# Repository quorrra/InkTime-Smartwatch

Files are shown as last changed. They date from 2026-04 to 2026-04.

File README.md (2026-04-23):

# InkTime — Open Source Smartwatch

InkTime is a low-cost, open-source smartwatch designed for extreme battery life and hackability.  
It features a **1.54" E-Paper display**, a **Nordic nRF52840 BLE SoC**, and a high-efficiency power system.

---

## 1) Block Diagram

The hardware architecture revolves around the nRF52840 MCU and a power system designed for month-long battery life.

````text
[ USB Type-C ]                              [ LiPo Battery (250mAh) ]
                 | 5V VBUS                                      |
                 v                                              |
          +---------------+                                     |
          |    BQ25180    | BAT                                 |
          | (Charger IC)  |<------------------------------------+
          +---------------+                                     v
                 | VSYS                                 +---------------+
                 v                                      |   MAX17048    |
          +---------------+                             | (Fuel Gauge)  |
          |    RT6160     |                             +---------------+
          | (Buck-Boost)  |                                     ^
          +---------------+                                     |
                 | 3.3V System Rail (VDD_3V3)                   |
                 |                                              |
 +---------------+----------------------------------------------+-----+
 |               |                                              |     |
 |               v                                              |     |
 |        +-------------+         I2C Bus                       |     |
 |        |  nRF52840   |<======================================+     |
 |        |    MCU      |                                             |
 |        |             |=== I2C ===> [ BMA423 Accelerometer ]        |
 |        |             |=== I2C ===> [ DRV2605L Driver ]-->[ Motor ] |
 |        |             |=== SPI ===> [ 1.54" E-paper Display ]       |
 |        |             |                       ^                      |
 |        |             |-- GPIO (Gate)         | VEPD (Switched Pwr) |
 |        +-------------+      |                |                      |
 |          ^  ^  ^  |         v                |                      |
 |          |  |  |  | +---------------+        |                      |
 +---------(|--|--|)-+-|  PFET Switch  |--------+                      |
            |  |  |  | +---------------+                               |
 [Up]-------+  |  |  |                                                 |
           [Down] |  +--- [ 2.4GHz Antenna ] - - BLE - - [ Companion Phone ]
                  |
              [Enter/Esc]
````

---

## 2) Bill of Materials (BOM)

All components are selected from the JLC Parts library for easy manufacturing and assembly.

| RefDes | Component | Description | JLC Part # | Datasheet |
|---|---|---|---|---|
| U1 | nRF52840 | BLE SoC, Cortex-M4F | [C137156](https://jlcpcb.com/partdetail/C190794) | BLE, Native USB |
| IC1 | BQ25180 | Li-Ion Charger | [C2907455](https://jlcpcb.com/partdetail/C3682423) |Safe USB power-path |
| IC9 | RT6160AWSC | Buck-Boost Converter | [C2834376](https://jlcpcb.com/partdetail/C7065276) | 3.3V System Rail |
| U3 | MAX17048G | I2C Fuel Gauge | [C146603](https://jlcpcb.com/partdetail/C2682616) | 1-Cell Battery Monitor |
| IC3 | BMA423 | 3-axis Accelerometer | [C224345](https://jlcpcb.com/partdetail/C5242966) | Embedded pedometer |
| IC4 | DRV2605YZFR | Haptic Driver | [C146312](https://jlcpcb.com/partdetail/C527464) | For ERM motor |
| J4 | KH-TYPE-C-16P  | USB-C Connector | [C319148](https://jlcpcb.com/partdetail/C7528806) |High-side power switch |

---

## 3) Hardware Functionality

### 3.1 Power Management System
- The watch is powered by a **250mAh LiPo battery**.
- **Charging:** BQ25180 handles USB charging (5V VBUS) and system power-path management.
- **Regulation:** RT6160 buck-boost ensures a stable **3.3V rail** even when battery voltage drops below 3.3V.
- **Fuel Gauge:** MAX17048 uses ModelGauge for accurate **SoC (%)** via I2C, without a sense resistor.

### 3.2 Processing & Connectivity
The **nRF52840** is the central processor, running BLE for smartphone notifications and controlling peripherals over I2C/SPI.

### 3.3 Display & Haptics
- **E-Paper Display:** 1.54", ultra-low power (0W image retention), controlled via SPI.
- **Haptics:** DRV2605 drives an LRA motor for tactile alerts and alarms.

---

## 4) nRF52840 Pin Mapping

| Pin | Signal Name | Interface  | Function |
|---|---|---|---|
| P0.13 | SW_UP | GPIO (In)  | Up navigation button |
| P0.14 | SW_ENT | GPIO (In)  | Enter/Select button |
| P1.02 | SW_DN | GPIO (In)  | Down navigation button |
| P0.08 | I2C_SDA | I2C Data | Shared SDA (IMU, Charger, Gauge, Haptic) |
| P1.09 | I2C_SCL | I2C Clock  | Shared SCL (IMU, Charger, Gauge, Haptic) |
| P0.20 | EPD_RESET | GPIO (Out) | Display hardware reset |
| P0.22 | EPD_BUSY | GPIO (In)  | Display status pin |
| P0.12 | HAPTIC_EN | GPIO (Out) | Enable for DRV2605 haptic driver |
| P0.01 | EPD_DC | GPIO (Out) | Data/Command selector for E-paper |
| P0.03 | EPD_CS | SPI CS | Chip select for E-paper display |

---

## 5) Design & Manufacturing Details

### 5.1 PCB Stackup & Constraints
- **Stackup:** 4-layer PCB (Top, GND Plane, Power Plane, Bottom)
- **Thickness:** 1.0 mm (wearable-friendly)
- **Antenna:** 2.4 GHz PCB antenna at board edge with ground clearance for BLE performance

### 5.2 Component Selection
- **Passives:**  
  - Resistors: 0201 SMD  
  - Capacitors ≤100nF: 0201  
  - Capacitors >100nF: 0402 (unless otherwise specified)
- **Placement:** All components on TOP layer

### 5.3 Routing Rules
- **Power traces** (VCC, VUSB, VBUS, 3V3): 0.3 mm
- **Signal traces:** minimum 0.15 mm
- **Grounding:** solid Layer 2 GND plane + via stitching for EMI/thermal performance

---

## 6) Design Log & Decisions

- **4-layer decision:** moved from 2 to 4 layers to route the 24-pin E-paper connector.
- **GND plane:** Layer 2 kept continuous for RF reference and improved signal integrity.
- **Mechanical fit:** verified in 3D enclosure model (USB-C and buttons aligned with housing).

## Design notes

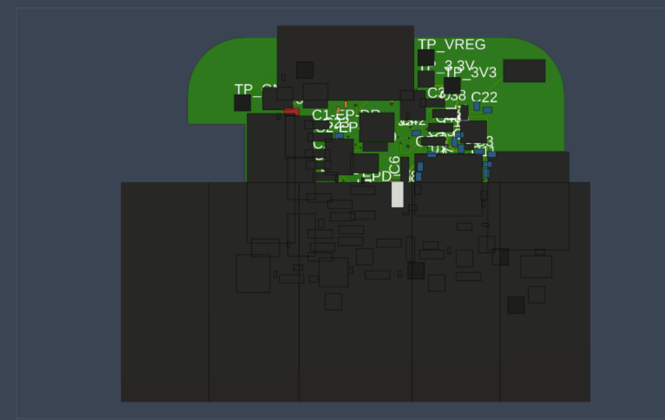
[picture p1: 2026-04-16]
Images/PCB_3D.png

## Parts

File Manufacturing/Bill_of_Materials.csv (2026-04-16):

Qty | Value | Device | Package | Parts | Description | ARROW_PART_NUMBER | ARROW_PRICE-STOCK | AVAILABILITY | CATEGORY | CHECK_PRICES | COPYRIGHT | DATASHEET | DESCRIPTION | DIGI-KEY_PART_NUMBER_1 | DIGI-KEY_PART_NUMBER_2 | DIGI-KEY_PART_NUMBER_3 | FREQUENCY | FREQUENCY_STABILITY | HEIGHT | JLCPCB | LOAD_CAPACITANCE | MANUFACTURER | MANUFACTURER_NAME | MANUFACTURER_PART_NUMBER | MF | MOUSER_PART_NUMBER | MOUSER_PRICE-STOCK | MP | MPN | OPERATING_TEMPERATURE | PACKAGE | PACKAGE_SIZE | PACKAGE_TYPE | PART_STATUS | POPULARITY | PRICE | PROD_ID | PURCHASE-URL | ROHS | SERIES | SNAPEDA_LINK | SPICEMODEL | SPICEPREFIX | SUBCATEGORY | THERMALLOSS | TOLERANCE | TP_SIGNAL_NAME | TYPE | VALUE
1 |  | ESP32_C6_LIBRARY_7_JUMPER_SJ | ESP32_C6_LIBRARY_7_JUMPER_SJ | SJ1 | SMD solder JUMPER |  |  |  |  |  |  |  |  |  |  |  |  |  |  |  |  |  |  |  |  |  |  |  |  |  |  |  |  |  | 3
1 | 0 | CPF0201D7K68C1_CPF0201D7K68C1 | CPF0201D7K68C1_0201 | R3 | 7.68k 0201 Thin Film Surface Mount Fixed Resistor +/-0.5% 0.031W CPF0201D7K68C1
2 | 0 | ERA-1AEB3401C_CPF0201D7K68C1 | ERA-1AEB3401C_0201 | R2, R4 | 7.68k 0201 Thin Film Surface Mount Fixed Resistor +/-0.5% 0.031W CPF0201D7K68C1
4 | 0.1uF | NORDIC_NRF_3_CAPACITOR_0201_L | NORDIC_NRF_3_RESC0201_L | C23, C27, C34, C42 | Generic chip capacitor
1 | 0.1uF/50V | NORDIC_NRF_3_CAPACITOR_0201_L | NORDIC_NRF_3_RESC0201_L | EPD_C5 | Generic chip capacitor
1 | 0.47 | CPF0201D7K68C1_CPF0201D7K68C1 | CPF0201D7K68C1_0201 | R1_EP_DR | 7.68k 0201 Thin Film Surface Mount Fixed Resistor +/-0.5% 0.031W CPF0201D7K68C1
1 | 1.0µF | ESP32_C6_LIBRARY_1_ESP32_WROVER_EAGLE-LTSPICE_CC0402 | ESP32_C6_LIBRARY_1_ESP32_WROVER_EAGLE-LTSPICE_C0402 | C15 | CAPACITOR, European symbol |  |  |  |  |  |  |  |  |  |  |  |  |  |  |  |  |  |  |  |  |  |  |  |  |  |  |  |  |  |  |  |  |  |  |  |  | NONE | C
5 | 100nF | NORDIC_NRF_3_CAPACITOR_0201_L | NORDIC_NRF_3_RESC0201_L | C5, C7, C8, C12, C19 | Generic chip capacitor
1 | 100pF | NORDIC_NRF_3_CAPACITOR_0201_L | NORDIC_NRF_3_RESC0201_L | C11 | Generic chip capacitor
1 | 10K | CPF0201D7K68C1_CPF0201D7K68C1 | CPF0201D7K68C1_0201 | R9 | 7.68k 0201 Thin Film Surface Mount Fixed Resistor +/-0.5% 0.031W CPF0201D7K68C1
4 | 10k | CPF0201D7K68C1_CPF0201D7K68C1 | CPF0201D7K68C1_0201 | R2_EP_DR, R5, R7, R8 | 7.68k 0201 Thin Film Surface Mount Fixed Resistor +/-0.5% 0.031W CPF0201D7K68C1
1 | 10k | ERA-1AEB3401C_CPF0201D7K68C1 | ERA-1AEB3401C_0201 | R_PWR_EPD | 7.68k 0201 Thin Film Surface Mount Fixed Resistor +/-0.5% 0.031W CPF0201D7K68C1
3 | 10uF | ESP32_C6_LIBRARY_1_ESP32_WROVER_EAGLE-LTSPICE_CC0402 | ESP32_C6_LIBRARY_1_ESP32_WROVER_EAGLE-LTSPICE_C0402 | C1-EP-DR, C24, C39 | CAPACITOR, European symbol |  |  |  |  |  |  |  |  |  |  |  |  |  |  |  |  |  |  |  |  |  |  |  |  |  |  |  |  |  |  |  |  |  |  |  |  | NONE | C
1 | 10µH | NORDIC_NRF_2_INDUCTOR_0402_L | NORDIC_NRF_2_RESC0402_L | L2 | Generic chip inductor
4 | 12pF | NORDIC_NRF_3_CAPACITOR_0201_L | NORDIC_NRF_3_RESC0201_L | C1, C2, C17, C18 | Generic chip capacitor
1 | 15nH | NORDIC_NRF_2_INDUCTOR_0402_L | NORDIC_NRF_2_RESC0402_L | L3 | Generic chip inductor
2 | 1pF | NORDIC_NRF_3_CAPACITOR_0201_L | NORDIC_NRF_3_RESC0201_L | C3, C4 | Generic chip capacitor
6 | 1uF | ESP32_C6_LIBRARY_1_ESP32_WROVER_EAGLE-LTSPICE_CC0402 | ESP32_C6_LIBRARY_1_ESP32_WROVER_EAGLE-LTSPICE_C0402 | C29, C30, C31, C32, C37, C38 | CAPACITOR, European symbol |  |  |  |  |  |  |  |  |  |  |  |  |  |  |  |  |  |  |  |  |  |  |  |  |  |  |  |  |  |  |  |  |  |  |  |  | NONE | C
9 | 1uF/50V | ESP32_C6_LIBRARY_1_ESP32_WROVER_EAGLE-LTSPICE_CC0402 | ESP32_C6_LIBRARY_1_ESP32_WROVER_EAGLE-LTSPICE_C0402 | EPD_C1, EPD_C2, EPD_C6, EPD_C7, EPD_C8, EPD_C9, EPD_C10, EPD_C11, EPD_C12 | CAPACITOR, European symbol |  |  |  |  |  |  |  |  |  |  |  |  |  |  |  |  |  |  |  |  |  |  |  |  |  |  |  |  |  |  |  |  |  |  |  |  | NONE | C
1 | 2.2 | CPF0201D7K68C1_CPF0201D7K68C1 | CPF0201D7K68C1_0201 | R_TYPE_SEL | 7.68k 0201 Thin Film Surface Mount Fixed Resistor +/-0.5% 0.031W CPF0201D7K68C1
3 | 2025-10-22_07-23-44_LIBRARY_EVP-AKE31ASW_EVP-AKE31A_PAN | 2025-10-22_07-23-44_LIBRARY_EVP-AKE31ASW_EVP-AKE31A_PAN | 2025-10-22_07-23-44_LIBRARY_SW_EVP-AKE31A_PAN | SW_DN, SW_ENT, SW_UP |  |  |  |  |  |  | Copyright (C) 2025 Ultra Librarian. All rights reserved. |  |  | P123437TR-ND | P123437CT-ND | P123437DKR-ND |  |  |  |  |  |  | Panasonic | EVP-AKE31A
1 | 20V/4.2A/52m?/1.4W | ESP32_C6_LIBRARY_4_ESP32_WROVER_SPARKFUN-DISCRETESEMI_MOSFET_PCH-DMG2305UX-7 | ESP32_C6_LIBRARY_4_ESP32_C6_LIBRARY_4_ESP32_C6_LIBRARY_4_ESP32_C6_LIBRARY_4_ESP32_WROVER_SPARKFUN-DISCRETESEMI_SOT23-3 | Q1 | P-channel MOSFETs |  |  |  |  |  |  |  |  |  |  |  |  |  |  |  |  |  |  |  |  |  |  |  |  |  |  |  |  |  |  |  | TRAN-14388 |  |  |  |  |  |  |  |  |  |  |  | 20V/4.2A/52m?/1.4W
2 | 22uF | ESP32_C6_LIBRARY_1_ESP32_WROVER_EAGLE-LTSPICE_CC0402 | ESP32_C6_LIBRARY_1_ESP32_WROVER_EAGLE-LTSPICE_C0402 | C25, C33 | CAPACITOR, European symbol |  |  |  |  |  |  |  |  |  |  |  |  |  |  |  |  |  |  |  |  |  |  |  |  |  |  |  |  |  |  |  |  |  |  |  |  | NONE | C
1 | 2450AT18B100E_2450AT18B100E | 2450AT18B100E_2450AT18B100E | 2450AT18B100E_ANTC3216X140N | ANT1 | Antennas 2.45GHz ANTENNA | 2450AT18B100E | https://www.arrow.com/en/products/2450at18b100e/johanson-dielectrics?utm_currency=USD&region=nac |  |  |  |  |  | Antennas 2.45GHz ANTENNA |  |  |  |  |  | 1.4mm |  |  |  | JOHANSON TECHNOLOGY | 2450AT18B100E |  | 609-2450AT18B100E | https://www.mouser.co.uk/ProductDetail/Johanson-Technology/2450AT18B100E?qs=yCnrNFeXz%252Bh5MFsFIXGZGA%3D%3D
1 | 3.9nH | NORDIC_NRF_2_INDUCTOR_0402_L | NORDIC_NRF_2_RESC0402_L | L1 | Generic chip inductor
1 | 32.768kHz | 9HT10 | XTAL330X1051X90N | X2 | Crystals 32.768KHz 12.5pF |  |  |  | Crystals |  |  | https://www.txccrystal.com/images/pdf/9ht10.pdf | 32.768 kHz ±20 ppm Crystal 12.5 pF 70 kOhms 2-SMD No Lead |  |  |  | 32.768 kHz | NA |  |  | 12.5 pF | TXC CORPORATION |  |  |  |  |  |  | 9HT10-32.768KDZF-T | -40°C ~ 85°C |  | 2-SMD No Lead | Surface Mount | Active |  |  |  |  | Compliant | 9HT10 |  |  |  | Oscillators |  | ±20 ppm |  | Resonators
1 | 32MHz | NORDIC_NRF_XTAL_32MHZ | NORDIC_NRF_BT-XTAL_2016_N | X1
2 | 3K3 | ERA-1AEB3401C_CPF0201D7K68C1 | ERA-1AEB3401C_0201 | R17, R18 | 7.68k 0201 Thin Film Surface Mount Fixed Resistor +/-0.5% 0.031W CPF0201D7K68C1
1 | 4.7uF | ESP32_C6_LIBRARY_1_ESP32_WROVER_EAGLE-LTSPICE_CC0402 | ESP32_C6_LIBRARY_1_ESP32_WROVER_EAGLE-LTSPICE_C0402 | C43 | CAPACITOR, European symbol |  |  |  |  |  |  |  |  |  |  |  |  |  |  |  |  |  |  |  |  |  |  |  |  |  |  |  |  |  |  |  |  |  |  |  |  | NONE | C
1 | 4.7uF/25V | ESP32_C6_LIBRARY_1_ESP32_WROVER_EAGLE-LTSPICE_CC0402 | ESP32_C6_LIBRARY_1_ESP32_WROVER_EAGLE-LTSPICE_C0402 | C2-EP-DR | CAPACITOR, European symbol |  |  |  |  |  |  |  |  |  |  |  |  |  |  |  |  |  |  |  |  |  |  |  |  |  |  |  |  |  |  |  |  |  |  |  |  | NONE | C
4 | 4.7µF | ESP32_C6_LIBRARY_1_ESP32_WROVER_EAGLE-LTSPICE_CC0402 | ESP32_C6_LIBRARY_1_ESP32_WROVER_EAGLE-LTSPICE_C0402 | C6, C14, C20, C21 | CAPACITOR, European symbol |  |  |  |  |  |  |  |  |  |  |  |  |  |  |  |  |  |  |  |  |  |  |  |  |  |  |  |  |  |  |  |  |  |  |  |  | NONE | C
1 | 47nF | NORDIC_NRF_3_CAPACITOR_0201_L | NORDIC_NRF_3_RESC0201_L | C16 | Generic chip capacitor
1 | 503480-2400_503480-2400 | 503480-2400_503480-2400 | 503480-2400_5034802400 | J1 | FFC & FPC Connectors 0.5mm FPC RA SMT Dual Contact 24Ckt |  |  |  |  |  |  |  | FFC & FPC Connectors 0.5mm FPC RA SMT Dual Contact 24Ckt |  |  |  |  |  | 1.87mm |  |  |  | Molex | 503480-2400 |  | 538-503480-2400 | https://www.mouser.co.uk/ProductDetail/Molex/503480-2400?qs=OAhjpuo3Vu7efIoxFh9AOw%3D%3D
2 | 5k1 | CPF0201D7K68C1_CPF0201D7K68C1 | CPF0201D7K68C1_0201 | R1_USB, R2_USB | 7.68k 0201 Thin Film Surface Mount Fixed Resistor +/-0.5% 0.031W CPF0201D7K68C1
1 | 68uH | NORDIC_NRF_2_INDUCTOR_0402_L | NORDIC_NRF_2_RESC0402_L | L5 | Generic chip inductor
1 | 820pF | NORDIC_NRF_3_CAPACITOR_0201_L | NORDIC_NRF_3_RESC0201_L | C9 | Generic chip capacitor
1 | BMA423_BMA423 | BMA423_BMA423 | BMA423_BMA423 | IC3 | Accelerometers Triaxial low-g 12bit Acceleration Sensor | BMA423 | https://www.arrow.com/en/products/bma423/bosch |  |  |  |  |  | Accelerometers Triaxial low-g 12bit Acceleration Sensor |  |  |  |  |  | 1mm |  |  |  | BOSCH | BMA423 |  | 262-BMA423 | https://www.mouser.co.uk/ProductDetail/Bosch-Sensortec/BMA423?qs=HXFqYaX1Q2xC%252BSgeGoX3mg%3D%3D
1 | BQ25180YBGR_BQ25180YBGR | BQ25180YBGR_BQ25180YBGR | BQ25180YBGR_BGA8C40P2X4_100X155X50 | IC1 | Charger IC Lithium Ion/Polymer, Lithium Iron Phosphate 8-DSBGA (1.6x1.1) | BQ25180YBGR | https://www.arrow.com/en/products/bq25180ybgr/texas-instruments?utm_currency=USD&region=nac |  |  |  |  |  | Charger IC Lithium Ion/Polymer | Lithium Iron Phosphate 8-DSBGA (1.6x1.1) |  |  |  |  |  | 0.5mm |  |  |  | Texas Instruments | BQ25180YBGR |  | 595-BQ25180YBGR | https://www.mouser.co.uk/ProductDetail/Texas-Instruments/BQ25180YBGR?qs=doiCPypUmgEWjAK%252BJAX6Tw%3D%3D
1 | DRV2605YZFR_DRV2605YZFR | DRV2605YZFR_DRV2605YZFR | DRV2605YZFR_BGA9C50P3X3_144X144X62 | IC2 | Haptic Driver for ERM/LRA with Built-In Library and Smart Loop Architecture | DRV2605YZFR | https://www.arrow.com/en/products/drv2605yzfr/texas-instruments?region=nac |  |  |  |  |  | Haptic Driver for ERM/LRA with Built-In Library and Smart Loop Architecture |  |  |  |  |  | 0.625mm |  |  |  | Texas Instruments | DRV2605YZFR
1 | ESP32_C6_LIBRARY_3_USBLC6-2SC6Y | ESP32_C6_LIBRARY_3_USBLC6-2SC6Y | ESP32_C6_LIBRARY_3_SOT95P280X145-6N | D3 | Low Cap. ESD Protection Auto SOT-23-6 STMicroelectronics USBLC6-2SC6Y, Dual Uni-Directional TVS Diode Array, 6-Pin SOT-23 |  |  | In Stock |  | https://www.snapeda.com/parts/USBLC6-2SC6Y/STMicroelectronics/view-part/?ref=eda |  |  | 17V Clamp 5A (8/20µs) Ipp Tvs Diode Surface Mount SOT-23-6 |  |  |  |  |  |  |  |  |  |  |  | STMicroelectronics |  |  | USBLC6-2SC6Y |  |  | SOT-23-6 STMicroelectronics |  |  |  |  | None |  |  |  |  | https://www.snapeda.com/parts/USBLC6-2SC6Y/STMicroelectronics/view-part/?ref=snap
1 | ESP32_C6_LIBRARY_6_SI1308EDL-T1-GE3 | ESP32_C6_LIBRARY_6_SI1308EDL-T1-GE3 | ESP32_C6_LIBRARY_6_SOT65P210X110-3N | Q3 | MOSFET N-Ch 30V 1.5A TrenchFET SC70 Vishay Si1308EDL-T1-GE3 N-channel MOSFET Transistor, 1.5 A, 30 V, 3-Pin SC-70 |  |  | In Stock |  | https://www.snapeda.com/parts/SI1308EDL-T1-GE3/Vishay+Siliconix/view-part/?ref=eda |  |  | Si1308EDL-T1-GE3 N-channel MOSFET Transistor | 1.5 A | 30 V | 3-Pin SC-70 | Siliconix / Vishay SI1308EDL-T1-GE3 |  |  |  |  |  |  |  |  |  |  |  | Vishay Siliconix |  |  | SI1308EDL-T1-GE3 |  |  | SOT-323 Vishay Semiconductor |  |  |  |  | None |  | https://www.snapeda.com/api/url_track_click_mouser/?unipart_id=274603&manufacturer=Vishay Siliconix&part_name=SI1308EDL-T1-GE3&search_term=None |  |  | https://www.snapeda.com/parts/SI1308EDL-T1-GE3/Vishay+Siliconix/view-part/?ref=snap
1 | ESP32_C6_LIBRARY_MAX17048G+T10 | ESP32_C6_LIBRARY_MAX17048G+T10 | ESP32_C6_LIBRARY_SON50P200X200X80-9N | U3 | Check availability |  |  | In Stock |  | https://www.snapeda.com/parts/MAX17048G+T10/Analog+Devices/view-part/?ref=eda |  |  | 3µA 1-Cell/2-Cell Fuel Gauge with ModelGauge |  |  |  |  |  |  |  |  |  |  |  | Analog Devices |  |  | MAX17048G+T10 |  |  | TDFN-8 Maxim |  |  |  |  | None |  | https://www.snapeda.com/api/url_track_click_mouser/?unipart_id=329239&manufacturer=Analog Devices&part_name=MAX17048G+T10&search_term=None |  |  | https://www.snapeda.com/parts/MAX17048G+T10/Analog+Devices/view-part/?ref=snap
14 | HECTOR_WATCH_1_TPTP20R | HECTOR_WATCH_1_TPTP20R | HECTOR_WATCH_1_TP20R | TP_3.3V, TP_3V3, TP_BAT_GND, TP_GND, TP_ON, TP_OP, TP_RESET, TP_SCL, TP_SDA, TP_SWDCLK, TP_SWDIO, TP_SWO, TP_VBAT, TP_VREG | Test pad |  |  |  |  |  |  |  |  |  |  |  |  |  |  |  |  |  |  |  |  |  |  |  |  |  |  |  |  |  | 2
1 | KH-TYPE-C-16P_KH-TYPE-C-16P | KH-TYPE-C-16P_KH-TYPE-C-16P | KH-TYPE-C-16P_KINGHELM_KH-TYPE-C-16P | J3 | Check availability |  |  | Not in stock |  | https://www.snapeda.com/parts/KH-TYPE-C-16P/Kinghelm/view-part/?ref=eda |  |  |  |  |  |  |  |  |  |  |  |  |  |  | kinghelm |  |  | KH-TYPE-C-16P |  |  | None |  |  |  |  | None |  |  |  |  | https://www.snapeda.com/parts/KH-TYPE-C-16P/Kinghelm/view-part/?ref=snap
3 | MBR0530 | ESP32_C6_LIBRARY_5_MBR0530 | ESP32_C6_LIBRARY_5_SOD3716X135N | D2, D4, D5 | ON SEMICONDUCTOR - MBR0530 - DIODE, SCHOTTKY, 0.5A, 30V, SOD-123 |  |  | In Stock |  | https://www.snapeda.com/parts/MBR0530/Onsemi/view-part/?ref=eda |  |  | Diode Schottky 30 V 500mA Surface Mount SOD-123 |  |  |  |  |  |  |  |  |  |  |  | ON Semiconductor |  |  | MBR0530 |  |  | SOD-123-2 ON Semiconductor |  |  |  |  | None |  | https://www.snapeda.com/api/url_track_click_mouser/?unipart_id=179458&manufacturer=ON Semiconductor&part_name=MBR0530&search_term=None |  |  | https://www.snapeda.com/parts/MBR0530/Onsemi/view-part/?ref=snap
1 | MLP2016SR47MT0S1_FTC252012SR47MBCA | MLP2016SR47MT0S1_FTC252012SR47MBCA | MLP2016SR47MT0S1_INDC2016X100N | L7 | SMD / SMT Inductors (Coils), L=0.47?H, L x W x T : |  |  |  |  |  |  |  | SMD / SMT Inductors (Coils) | L=0.47?H | L x W x T : |  |  |  |  |  | 1mm | https://jlcpcb.com/partdetail/6763488-FTC252012SR47MBCA/C5832368 |  |  | TDK | FTC252012SR47MBCA
3 | N.C. | NORDIC_NRF_3_CAPACITOR_0201_L | NORDIC_NRF_3_RESC0201_L | C10, C13, C22 | Generic chip capacitor
1 | NORDIC_NRF_4_NRF52840_QF | NORDIC_NRF_4_NRF52840_QF | NORDIC_NRF_4_AQFN50P700X700X85_HS-74N | U1 | nRF52840
1 | RT6160AWSC_RT6160AWSC | RT6160AWSC_RT6160AWSC | RT6160AWSC_BGA15C40P3X5_140X230X60 | IC9 | Buck-Boost Regulator Positive Output Step-Up/Step-Down I2C DC-DC Controller IC 15-WL-CSP (BSC) (1.4x2.3) |  |  |  |  |  |  |  | Buck-Boost Regulator Positive Output Step-Up/Step-Down I2C DC-DC Controller IC 15-WL-CSP (BSC) (1.4x2.3) |  |  |  |  |  | 0.6mm |  |  |  | RICHTEK | RT6160AWSC |  | 835-RT6160AWSC | https://www.mouser.co.uk/ProductDetail/Richtek/RT6160AWSC?qs=amGC7iS6iy%2FLd9PSoixZXQ%3D%3D
1 | TC2030-IDC_TC2030-IDC | TC2030-IDC_TC2030-IDC | TC2030-IDC_TC2030IDC | J2 | CABLE ADAPTER 6 POS |  |  |  |  |  |  |  | CABLE ADAPTER 6 POS |  |  |  |  |  | 19mm |  |  |  | Tag Connect | TC2030-IDC

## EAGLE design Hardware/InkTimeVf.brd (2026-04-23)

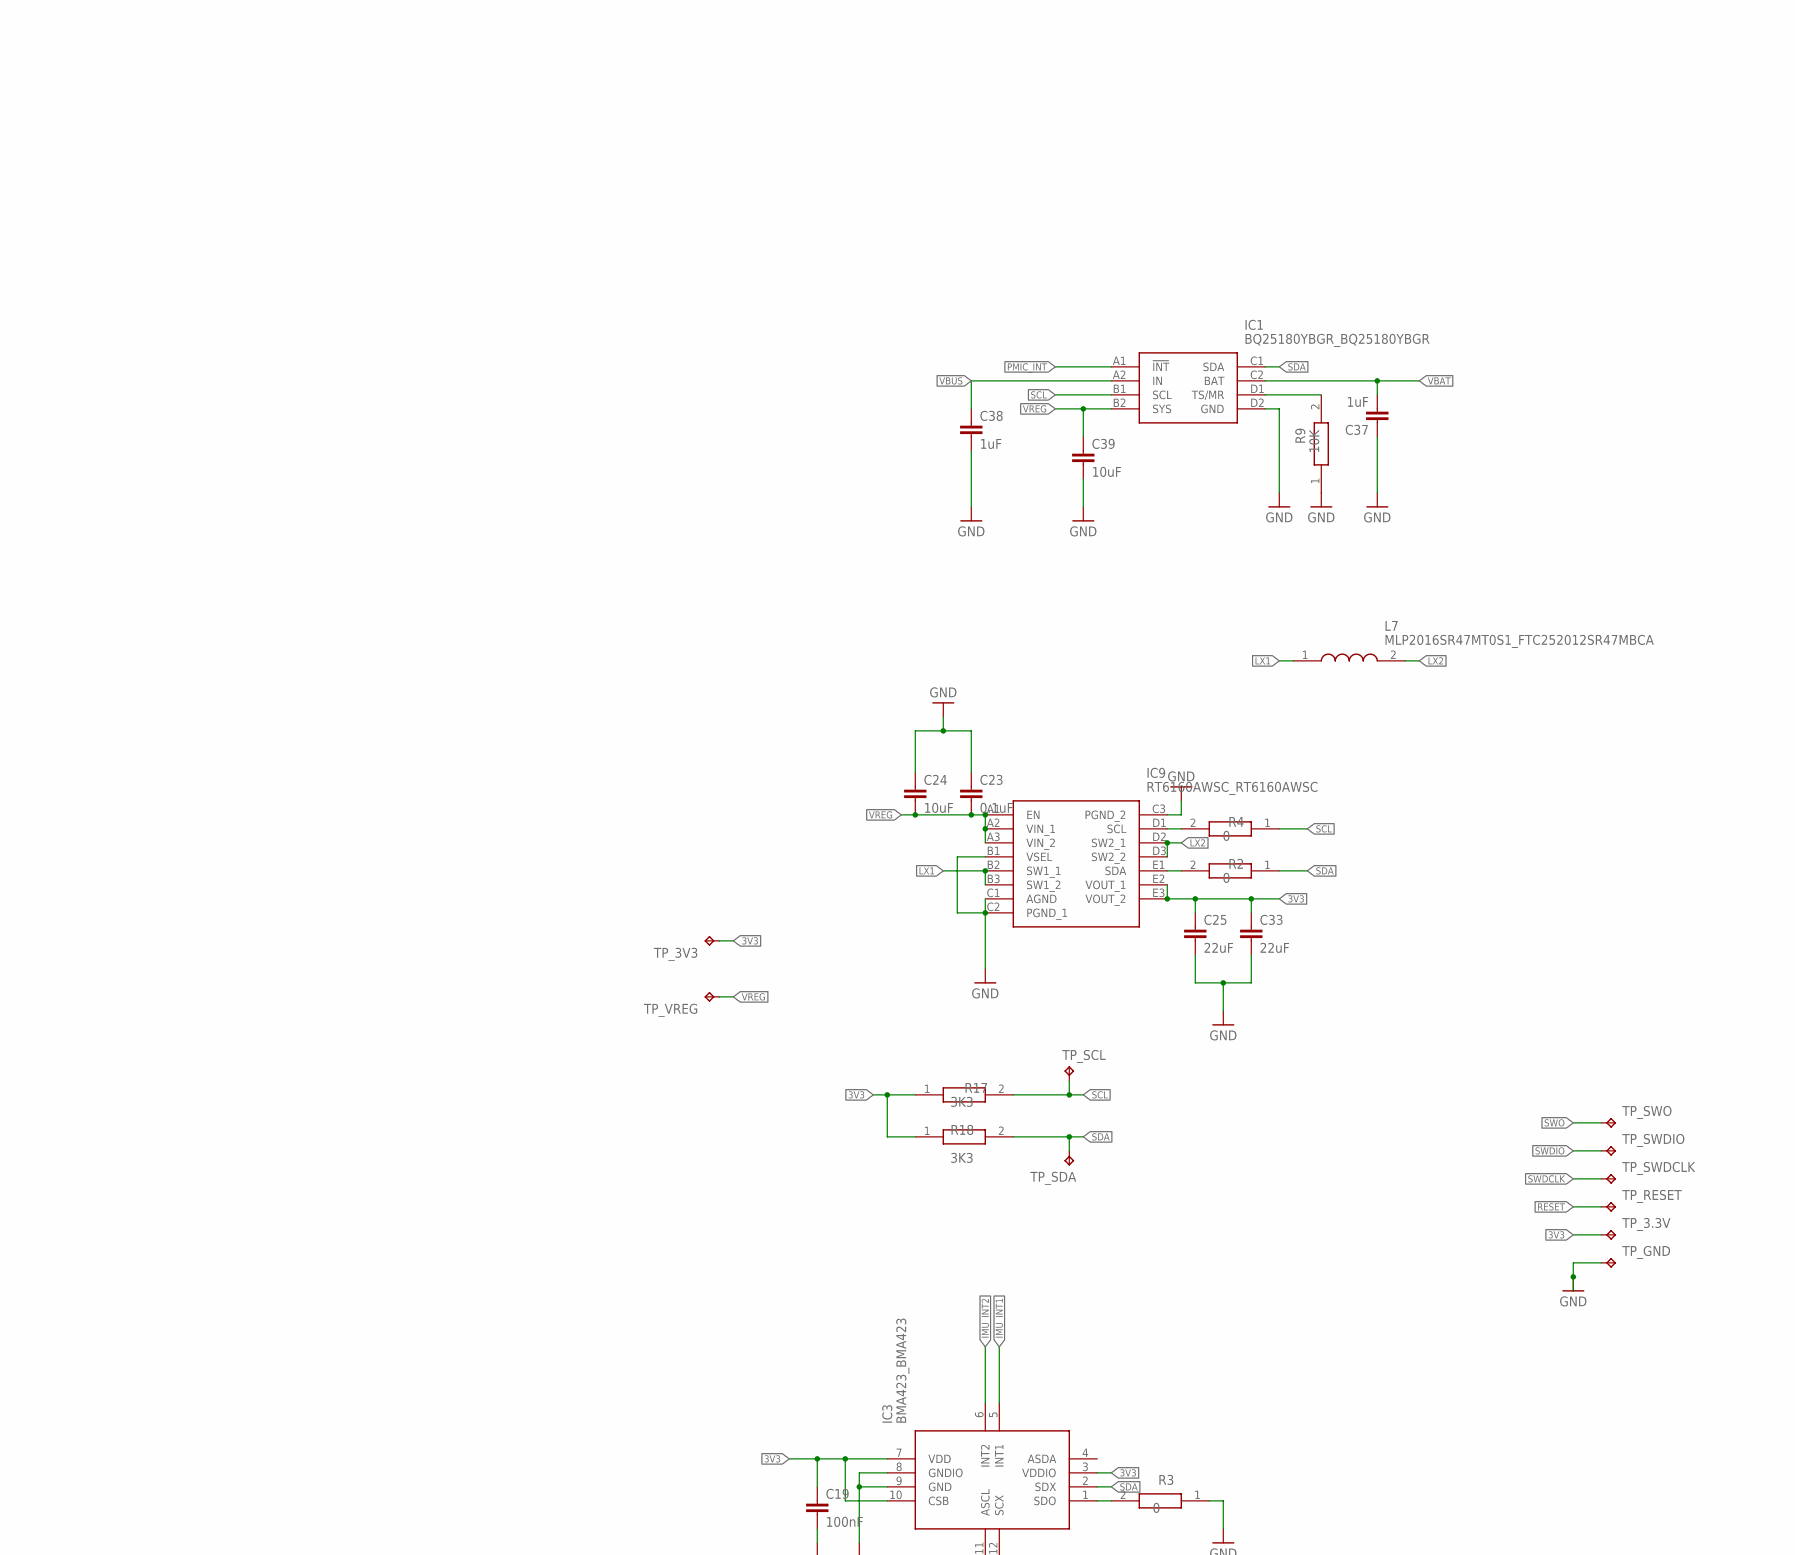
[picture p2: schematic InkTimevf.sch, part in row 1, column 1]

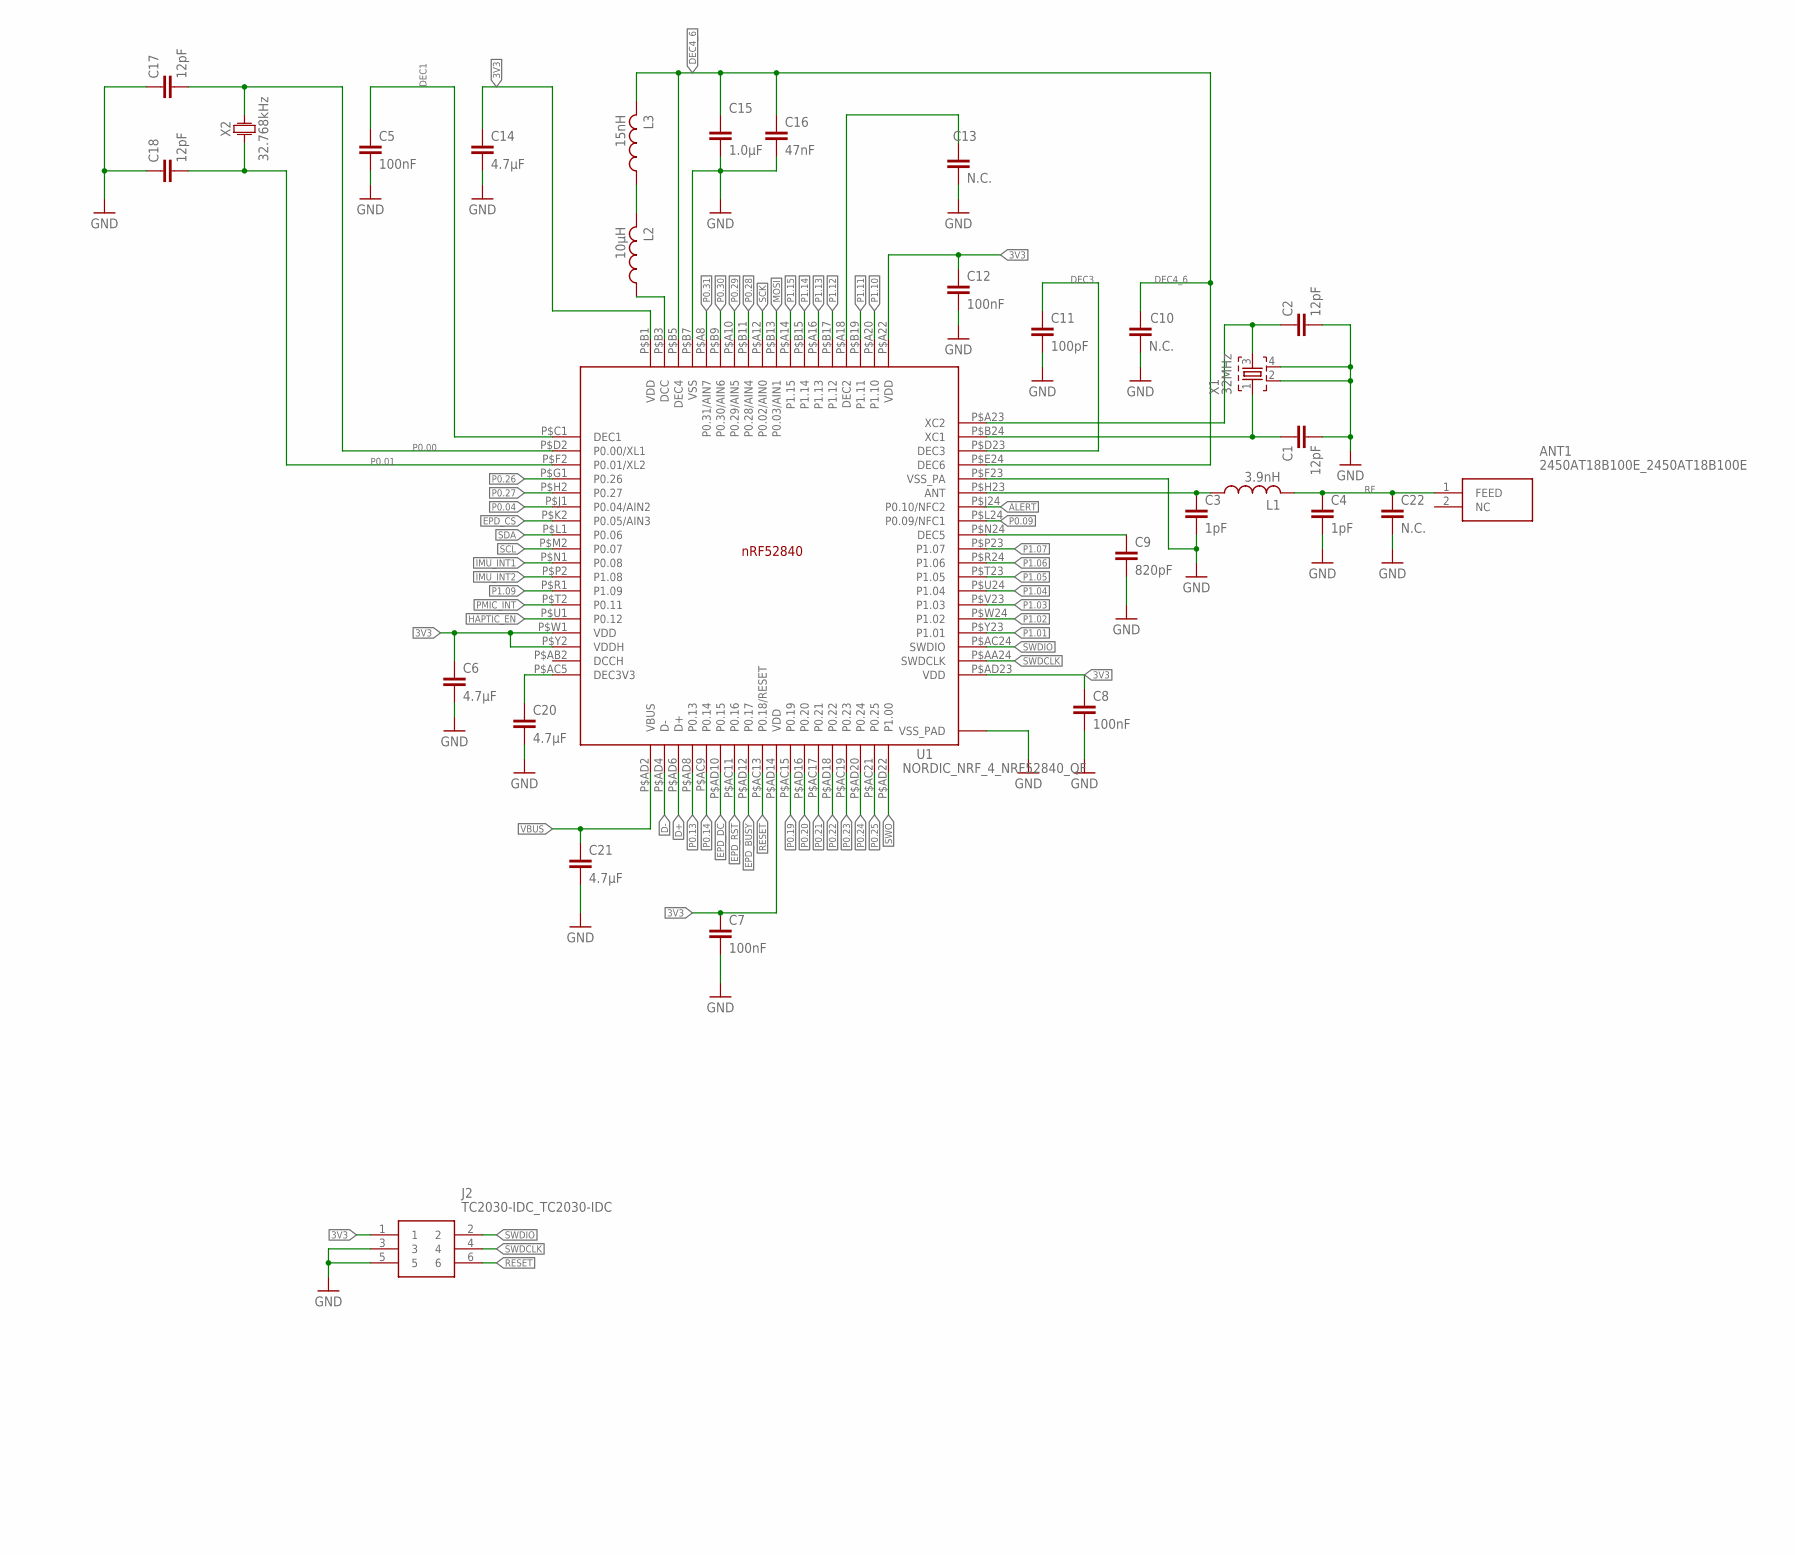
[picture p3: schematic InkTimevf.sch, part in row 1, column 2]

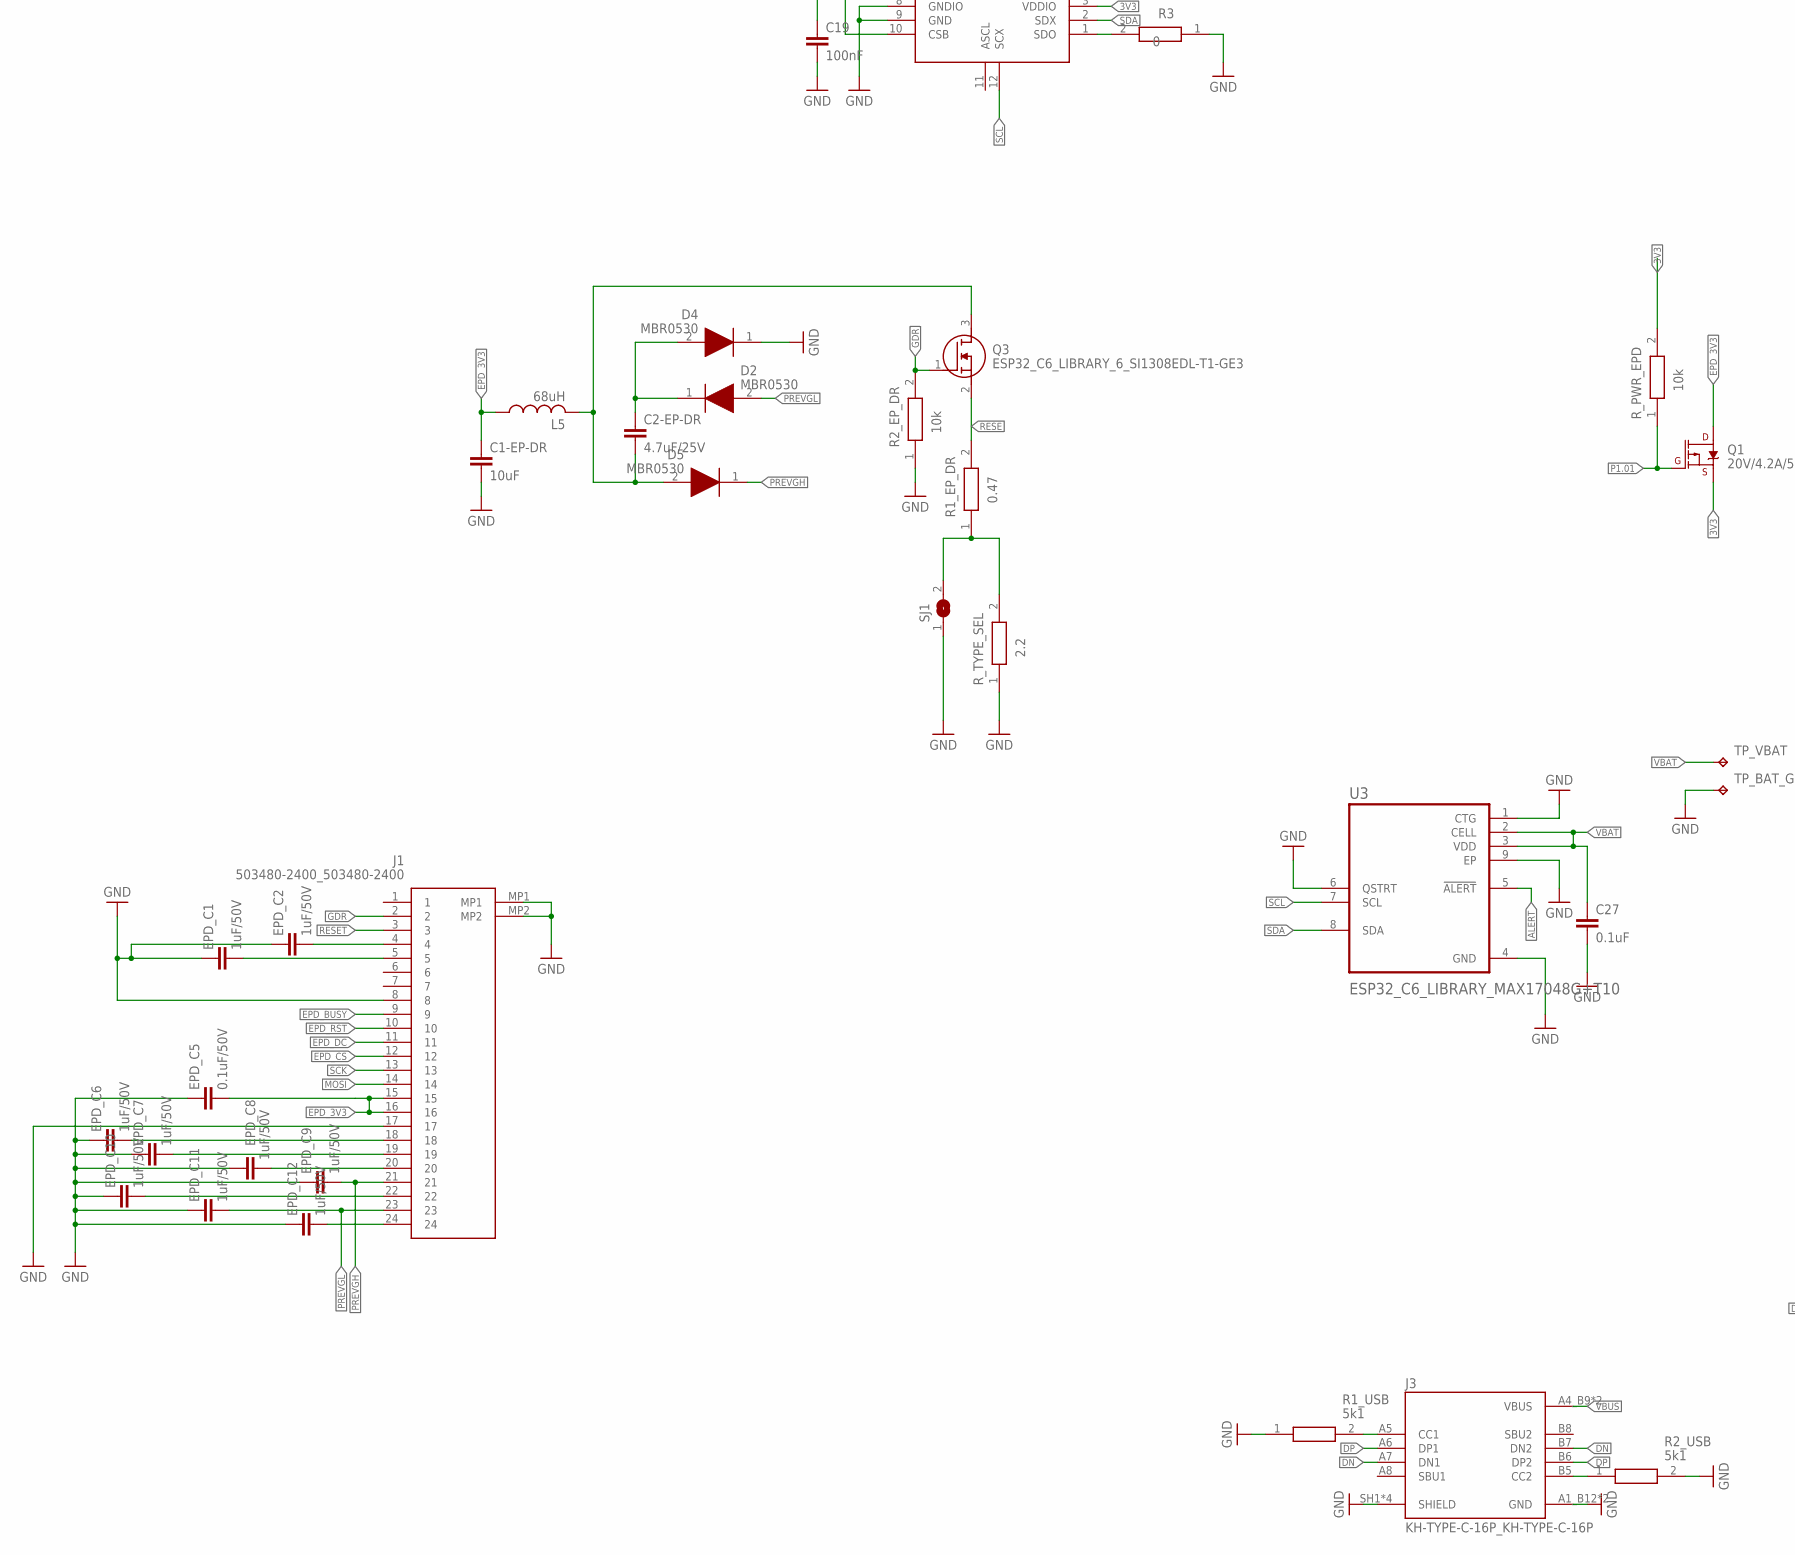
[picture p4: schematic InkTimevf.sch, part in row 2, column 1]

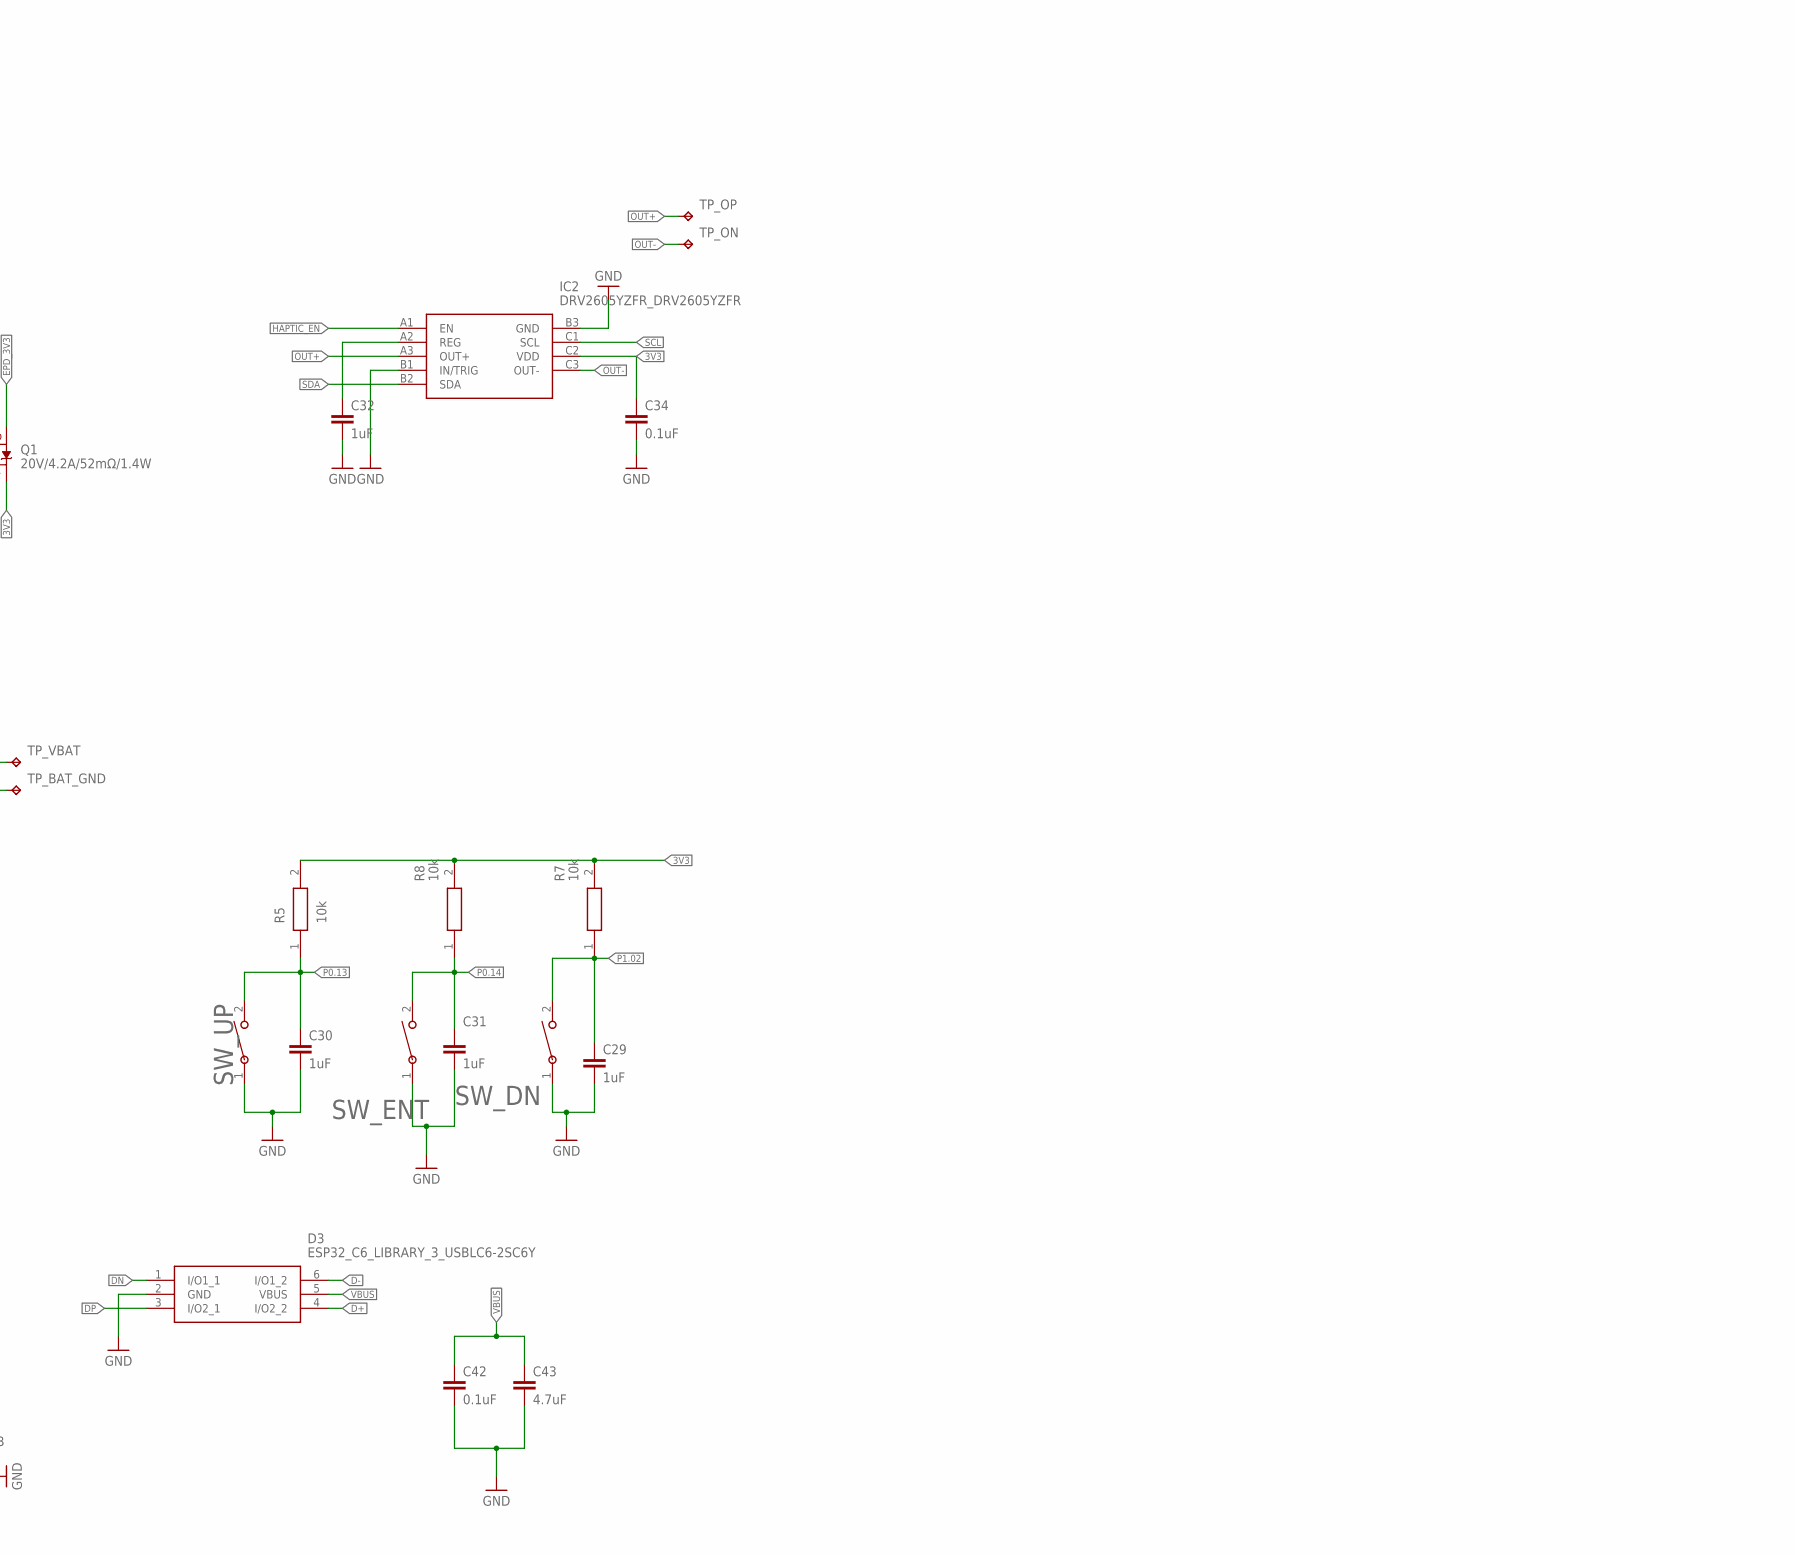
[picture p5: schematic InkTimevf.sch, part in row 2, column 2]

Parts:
ANT1: 2450AT18B100E_2450AT18B100E; 2450AT18B100E_ANTC3216X140N
C1, C2, C17, C18: 12pF; NORDIC_NRF_3_RESC0201_L
C1-EP-DR, C24, C39: 10uF; ESP32_C6_LIBRARY_1_ESP32_WROVER_EAGLE-LTSPICE_C0402
C2-EP-DR: 4.7uF/25V; ESP32_C6_LIBRARY_1_ESP32_WROVER_EAGLE-LTSPICE_C0402
C3, C4: 1pF; NORDIC_NRF_3_RESC0201_L
C5, C7, C8, C12, C19: 100nF; NORDIC_NRF_3_RESC0201_L
C6, C14, C20, C21: 4.7µF; ESP32_C6_LIBRARY_1_ESP32_WROVER_EAGLE-LTSPICE_C0402
C9: 820pF; NORDIC_NRF_3_RESC0201_L
C10, C13, C22: N.C.; NORDIC_NRF_3_RESC0201_L
C11: 100pF; NORDIC_NRF_3_RESC0201_L
C15: 1.0µF; ESP32_C6_LIBRARY_1_ESP32_WROVER_EAGLE-LTSPICE_C0402
C16: 47nF; NORDIC_NRF_3_RESC0201_L
C23, C27, C34, C42: 0.1uF; NORDIC_NRF_3_RESC0201_L
C25, C33: 22uF; ESP32_C6_LIBRARY_1_ESP32_WROVER_EAGLE-LTSPICE_C0402
C29, C30, C31, C32, C37, C38: 1uF; ESP32_C6_LIBRARY_1_ESP32_WROVER_EAGLE-LTSPICE_C0402
C43: 4.7uF; ESP32_C6_LIBRARY_1_ESP32_WROVER_EAGLE-LTSPICE_C0402
D2, D4, D5: MBR0530; ESP32_C6_LIBRARY_5_SOD3716X135N
D3: ESP32_C6_LIBRARY_3_USBLC6-2SC6Y; ESP32_C6_LIBRARY_3_SOT95P280X145-6N
EPD_C1, EPD_C2, EPD_C6, EPD_C7, EPD_C8, EPD_C9, EPD_C10, EPD_C11, EPD_C12: 1uF/50V; ESP32_C6_LIBRARY_1_ESP32_WROVER_EAGLE-LTSPICE_C0402
EPD_C5: 0.1uF/50V; NORDIC_NRF_3_RESC0201_L
IC1: BQ25180YBGR_BQ25180YBGR; BQ25180YBGR_BGA8C40P2X4_100X155X50
IC2: DRV2605YZFR_DRV2605YZFR; DRV2605YZFR_BGA9C50P3X3_144X144X62
IC3: BMA423_BMA423
IC9: RT6160AWSC_RT6160AWSC; RT6160AWSC_BGA15C40P3X5_140X230X60
J1: 503480-2400_503480-2400; 503480-2400_5034802400
J2: TC2030-IDC_TC2030-IDC; TC2030-IDC_TC2030IDC
J3: KH-TYPE-C-16P_KH-TYPE-C-16P; KH-TYPE-C-16P_KINGHELM_KH-TYPE-C-16P
L1: 3.9nH; NORDIC_NRF_2_RESC0402_L
L2: 10µH; NORDIC_NRF_2_RESC0402_L
L3: 15nH; NORDIC_NRF_2_RESC0402_L
L5: 68uH; NORDIC_NRF_2_RESC0402_L
L7: MLP2016SR47MT0S1_FTC252012SR47MBCA; MLP2016SR47MT0S1_INDC2016X100N
Q1: 20V/4.2A/52mΩ/1.4W; ESP32_C6_LIBRARY_4_ESP32_C6_LIBRARY_4_ESP32_C6_LIBRARY_4_ES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
Q3: ESP32_C6_LIBRARY_6_SI1308EDL-T1-GE3; ESP32_C6_LIBRARY_6_SOT65P210X110-3N
R1_EP_DR: 0.47; CPF0201D7K68C1_0201
R1_USB, R2_USB: 5k1; CPF0201D7K68C1_0201
R2, R4: 0; ERA-1AEB3401C_0201
R2_EP_DR, R5, R7, R8: 10k; CPF0201D7K68C1_0201
R3: 0; CPF0201D7K68C1_0201
R9: 10K; CPF0201D7K68C1_0201
R17, R18: 3K3; ERA-1AEB3401C_0201
R_PWR_EPD: 10k; ERA-1AEB3401C_0201
R_TYPE_SEL: 2.2; CPF0201D7K68C1_0201
SJ1: ESP32_C6_LIBRARY_7_JUMPER_SJ
SW_DN: 2025-10-22_07-23-44_LIBRARY_EVP-AKE31ASW_EVP-AKE3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; 2025-10-22_07-23-44_LIBRARY_SW_EVP-AKE31A_PAN
SW_ENT: 2025-10-22_07-23-44_LIBRARY_EVP-AKE31ASW_EVP-AKE3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; 2025-10-22_07-23-44_LIBRARY_SW_EVP-AKE31A_PAN
SW_UP: 2025-10-22_07-23-44_LIBRARY_EVP-AKE31ASW_EVP-AKE3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; 2025-10-22_07-23-44_LIBRARY_SW_EVP-AKE31A_PAN
TP_3.3V, TP_3V3: HECTOR_WATCH_1_TPTP20R; HECTOR_WATCH_1_TP20R
TP_BAT_GND: HECTOR_WATCH_1_TPTP20R; HECTOR_WATCH_1_TP20R
TP_GND: HECTOR_WATCH_1_TPTP20R; HECTOR_WATCH_1_TP20R
TP_ON: HECTOR_WATCH_1_TPTP20R; HECTOR_WATCH_1_TP20R
TP_OP: HECTOR_WATCH_1_TPTP20R; HECTOR_WATCH_1_TP20R
TP_RESET: HECTOR_WATCH_1_TPTP20R; HECTOR_WATCH_1_TP20R
TP_SCL: HECTOR_WATCH_1_TPTP20R; HECTOR_WATCH_1_TP20R
TP_SDA: HECTOR_WATCH_1_TPTP20R; HECTOR_WATCH_1_TP20R
TP_SWDCLK: HECTOR_WATCH_1_TPTP20R; HECTOR_WATCH_1_TP20R
TP_SWDIO: HECTOR_WATCH_1_TPTP20R; HECTOR_WATCH_1_TP20R
TP_SWO: HECTOR_WATCH_1_TPTP20R; HECTOR_WATCH_1_TP20R
TP_VBAT: HECTOR_WATCH_1_TPTP20R; HECTOR_WATCH_1_TP20R
TP_VREG: HECTOR_WATCH_1_TPTP20R; HECTOR_WATCH_1_TP20R
U1: NORDIC_NRF_4_NRF52840_QF; NORDIC_NRF_4_AQFN50P700X700X85_HS-74N
U3: ESP32_C6_LIBRARY_MAX17048G+T10; ESP32_C6_LIBRARY_SON50P200X200X80-9N
X1: 32MHz; NORDIC_NRF_BT-XTAL_2016_N
X2: 32.768kHz; XTAL330X1051X90N

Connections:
3V3: C6.1, C7.1, C8.1, C12.1, C14.1, C19.1, C25.1, C33.1, C34.1, IC2.C2 (VDD), IC3.3 (VDDIO), IC3.7 (VDD), IC3.10 (CSB), IC9.E2 (VOUT_1), IC9.E3 (VOUT_2), J2.1, Q1.2 (S), R5.2, R7.2, R8.2, R17.1, R18.1, R_PWR_EPD.2, TP_3.3V.TP, TP_3V3.TP, U1.P$A22 (VDD), U1.P$AD14 (VDD), U1.P$AD23 (VDD), U1.P$B1 (VDD), U1.P$W1 (VDD), U1.P$Y2 (VDDH)
ALERT: U1.P$J24 (P0.10/NFC2), U3.5 (!ALERT)
D+: D3.4 (I/O2_2), U1.P$AD6 (D+)
D-: D3.6 (I/O1_2), U1.P$AD4 (D-)
DEC1: C5.1, U1.P$C1 (DEC1)
DEC3: C11.1, U1.P$D23 (DEC3)
DEC4_6: C10.1, C15.1, C16.1, L3.2, U1.P$B5 (DEC4), U1.P$E24 (DEC6)
DN: D3.1 (I/O1_1), J3.A7 (DN1), J3.B7 (DN2)
DP: D3.3 (I/O2_1), J3.A6 (DP1), J3.B6 (DP2)
EPD_3V3: C1-EP-DR.1, EPD_C5.2, J1.15, J1.16, L5.1, Q1.3 (D)
EPD_BUSY: J1.9, U1.P$AD12 (P0.17)
EPD_CS: J1.12, U1.P$K2 (P0.05/AIN3)
EPD_DC: J1.11, U1.P$AD10 (P0.15)
EPD_RST: J1.10, U1.P$AC11 (P0.16)
GDR: J1.2, Q3.1 (G), R2_EP_DR.2
GND: C1.2, C1-EP-DR.2, C2.2, C3.2, C4.2, C5.2, C6.2, C7.2, C8.2, C9.2, C10.2, C11.2, C12.2, C13.2, C14.2, C15.2, C16.2, C17.1, C18.1, C19.2, C20.2, C21.2, C22.2, C23.1, C24.1, C25.2, C27.2, C29.2, C30.2, C31.2, C32.2, C33.2, C34.2, C37.1, C38.2, C39.2, C42.2, C43.2, D3.2 (GND), D4.1 (K), EPD_C1.1, EPD_C2.1, EPD_C5.1, EPD_C6.1, EPD_C7.1, EPD_C8.1, EPD_C9.1, EPD_C10.1, EPD_C11.1, EPD_C12.1, IC1.D2 (GND), IC2.B1 (IN/TRIG), IC2.B3 (GND), IC3.8 (GNDIO), IC3.9 (GND), IC9.B1 (VSEL), IC9.C1 (AGND), IC9.C2 (PGND_1), IC9.C3 (PGND_2), J1.8, J1.17, J1.MP1, J1.MP2, J2.3, J2.5, J3.A1_B12 (GND), J3.A12_B1 (GND), J3.SH1 (SHIELD), J3.SH2 (SHIELD), J3.SH3 (SHIELD), J3.SH4 (SHIELD), R1_USB.1, R2_EP_DR.1, R2_USB.2, R3.1, R9.1, R_TYPE_SEL.1, SJ1.1, SW_DN.1, SW_ENT.1, SW_UP.1, TP_BAT_GND.TP, TP_GND.TP, U1.P$74 (VSS_PAD), U1.P$75 (VSS_PAD), U1.P$76 (VSS_PAD), U1.P$77 (VSS_PAD), U1.P$78 (VSS_PAD), U1.P$79 (VSS_PAD), U1.P$80 (VSS_PAD), U1.P$81 (VSS_PAD), U1.P$82 (VSS_PAD), U1.P$83 (VSS_PAD), U1.P$84 (VSS_PAD), U1.P$85 (VSS_PAD), U1.P$86 (VSS_PAD), U1.P$87 (VSS_PAD), U1.P$88 (VSS_PAD), U1.P$89 (VSS_PAD), U1.P$90 (VSS_PAD), U1.P$B7 (VSS), U1.P$F23 (VSS_PA), U3.1 (CTG), U3.4 (GND), U3.6 (QSTRT), U3.9 (EP), X1.2, X1.4
HAPTIC_EN: IC2.A1 (EN), U1.P$U1 (P0.12)
IMU_INT1: IC3.5 (INT1), U1.P$N1 (P0.08)
IMU_INT2: IC3.6 (INT2), U1.P$P2 (P1.08)
LX1: IC9.B2 (SW1_1), IC9.B3 (SW1_2), L7.1
LX2: IC9.D2 (SW2_1), IC9.D3 (SW2_2), L7.2
MOSI: J1.14, U1.P$B13 (P0.03/AIN1)
unnamed: IC1.D1 (TS/MR), R9.2
unnamed: C3.1, L1.1, U1.P$H23 (ANT)
unnamed: L2.2, L3.1
unnamed: IC9.D1 (SCL), R4.2
unnamed: C1.1, U1.P$B24 (XC1), X1.1
unnamed: C2.1, U1.P$A23 (XC2), X1.3
unnamed: IC9.E1 (SDA), R2.2
unnamed: C20.1, U1.P$AC5 (DEC3V3)
unnamed: C2-EP-DR.2, D5.2 (A), L5.2, Q3.3 (D)
unnamed: C9.1, U1.P$N24 (DEC5)
unnamed: C13.1, U1.P$A18 (DEC2)
unnamed: EPD_C7.2, J1.19
unnamed: C2-EP-DR.1, D2.1 (K), D4.2 (A)
unnamed: R1_EP_DR.1, R_TYPE_SEL.2, SJ1.2
unnamed: IC3.1 (SDO), R3.2
unnamed: C32.1, IC2.A2 (REG)
unnamed: EPD_C2.2, J1.4
unnamed: EPD_C1.2, J1.5
unnamed: L2.1, U1.P$B3 (DCC)
unnamed: EPD_C6.2, J1.18
unnamed: EPD_C8.2, J1.20
unnamed: EPD_C10.2, J1.22
unnamed: EPD_C12.2, J1.24
unnamed: J3.B5 (CC2), R2_USB.1
unnamed: J3.A5 (CC1), R1_USB.2
OUT+: IC2.A3 (OUT+), TP_OP.TP
OUT-: IC2.C3 (OUT-), TP_ON.TP
P0.00: C17.2, U1.P$D2 (P0.00/XL1), X2.2
P0.01: C18.2, U1.P$F2 (P0.01/XL2), X2.1
P0.04: U1.P$J1 (P0.04/AIN2)
P0.09: U1.P$L24 (P0.09/NFC1)
P0.13: C30.1, R5.1, SW_UP.2, U1.P$AD8 (P0.13)
P0.14: C31.1, R8.1, SW_ENT.2, U1.P$AC9 (P0.14)
P0.19: U1.P$AC15 (P0.19)
P0.20: U1.P$AD16 (P0.20)
P0.21: U1.P$AC17 (P0.21)
P0.22: U1.P$AD18 (P0.22)
P0.23: U1.P$AC19 (P0.23)
P0.24: U1.P$AD20 (P0.24)
P0.25: U1.P$AC21 (P0.25)
P0.26: U1.P$G1 (P0.26)
P0.27: U1.P$H2 (P0.27)
P0.28: U1.P$B11 (P0.28/AIN4)
P0.29: U1.P$A10 (P0.29/AIN5)
P0.30: U1.P$B9 (P0.30/AIN6)
P0.31: U1.P$A8 (P0.31/AIN7)
P1.01: Q1.1 (G), R_PWR_EPD.1, U1.P$Y23 (P1.01)
P1.02: C29.1, R7.1, SW_DN.2, U1.P$W24 (P1.02)
P1.03: U1.P$V23 (P1.03)
P1.04: U1.P$U24 (P1.04)
P1.05: U1.P$T23 (P1.05)
P1.06: U1.P$R24 (P1.06)
P1.07: U1.P$P23 (P1.07)
P1.09: U1.P$R1 (P1.09)
P1.10: U1.P$A20 (P1.10)
P1.11: U1.P$B19 (P1.11)
P1.12: U1.P$B17 (P1.12)
P1.13: U1.P$A16 (P1.13)
P1.14: U1.P$B15 (P1.14)
P1.15: U1.P$A14 (P1.15)
PMIC_INT: IC1.A1 (!INT), U1.P$T2 (P0.11)
PREVGH: D5.1 (K), EPD_C9.2, J1.21
PREVGL: D2.2 (A), EPD_C11.2, J1.23
RESE: Q3.2 (S), R1_EP_DR.2
RESET: J1.3, J2.6, TP_RESET.TP, U1.P$AC13 (P0.18/RESET)
RF: ANT1.1 (FEED), C4.1, C22.1, L1.2
SCK: J1.13, U1.P$A12 (P0.02/AIN0)
SCL: IC1.B1 (SCL), IC2.C1 (SCL), IC3.12 (SCX), R4.1, R17.2, TP_SCL.TP, U1.P$M2 (P0.07), U3.7 (SCL)
SDA: IC1.C1 (SDA), IC2.B2 (SDA), IC3.2 (SDX), R2.1, R18.2, TP_SDA.TP, U1.P$L1 (P0.06), U3.8 (SDA)
SWDCLK: J2.4, TP_SWDCLK.TP, U1.P$AA24 (SWDCLK)
SWDIO: J2.2, TP_SWDIO.TP, U1.P$AC24 (SWDIO)
SWO: TP_SWO.TP, U1.P$AD22 (P1.00)
VBAT: C27.1, C37.2, IC1.C2 (BAT), TP_VBAT.TP, U3.2 (CELL), U3.3 (VDD)
VBUS: C21.1, C38.1, C42.1, C43.1, D3.5 (VBUS), IC1.A2 (IN), J3.A4_B9 (VBUS), J3.A9_B4 (VBUS), U1.P$AD2 (VBUS)
VREG: C23.2, C24.2, C39.1, IC1.B2 (SYS), IC9.A1 (EN), IC9.A2 (VIN_1), IC9.A3 (VIN_2), TP_VREG.TP

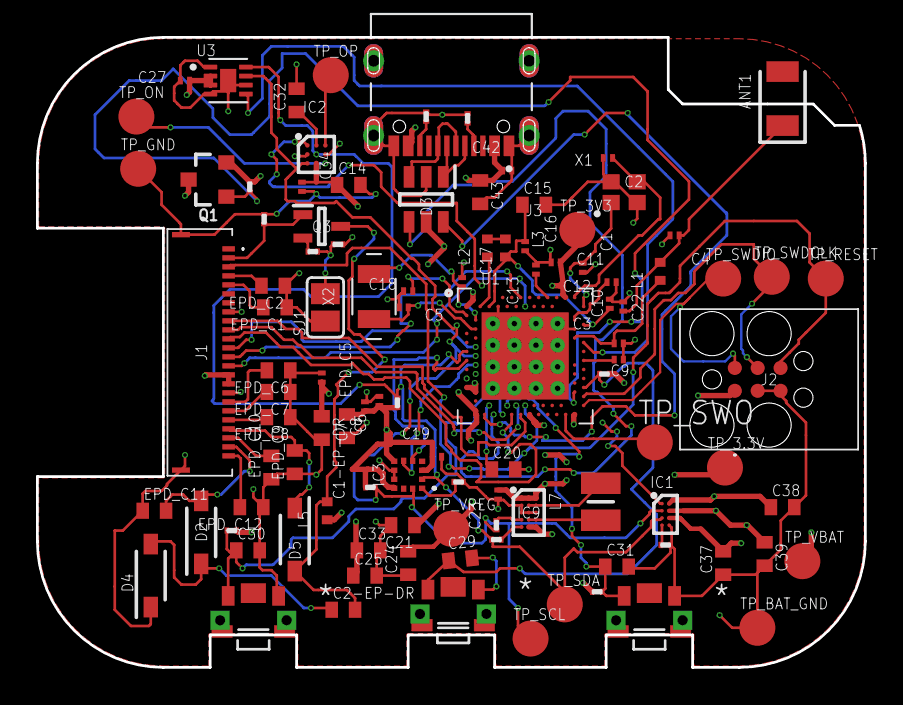
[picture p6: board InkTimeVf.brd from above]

Board: 4 copper layers, 46.0 x 35.0 mm, 105 parts (0 on the bottom side), 70 nets.

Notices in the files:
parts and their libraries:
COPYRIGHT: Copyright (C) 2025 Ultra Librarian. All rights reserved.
